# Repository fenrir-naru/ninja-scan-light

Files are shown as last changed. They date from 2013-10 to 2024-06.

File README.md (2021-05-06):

NinjaScan-Light
===============

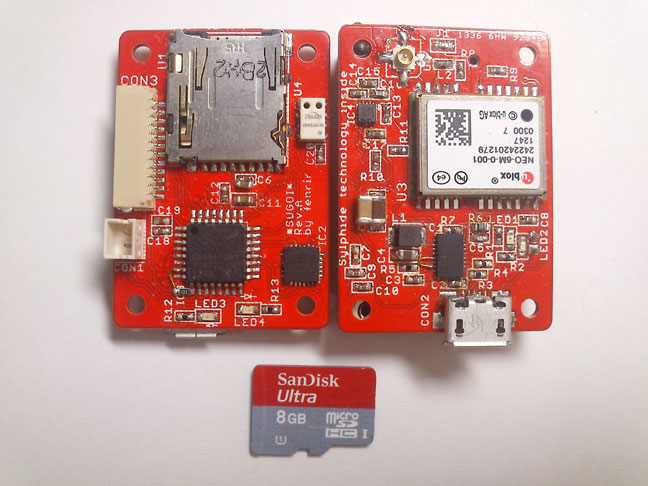
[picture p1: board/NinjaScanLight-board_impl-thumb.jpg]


[NinjaScan-Light](https://github.com/fenrir-naru/ninja-scan-light/wiki) is an ultra-small (1.0 x 1.4 inch, approximately 26 x 36 mm) motion logger. 
It consists of
 
1. Silicon Laboratories C8051F381 MCU providing USB connectability, 
1. u-blox NEO-6 series GPS receiver, 
1. 6 DOF inertial sensor, Invensense MPU-6000 (ver.1), or Invensense MPU-9250 (ver.2), 
1. 3-axis magnetic sensor, Freescale MAG3110 (ver.1), or Invensense MPU-9250 (ver.2), 
1. Pressure sensor, Measurement specialties MS5611, 
1. Power management including Li-Ion battery charger, Linear Technology LTC3550, and 
1. MicroSD supporting SDHC/FAT32. 

**More information in [Wiki](https://github.com/fenrir-naru/ninja-scan-light/wiki).**

## Additional information
* Firmware binaries are released in [github](https://github.com/fenrir-naru/ninja-scan-light/releases).
* External links for [related tools](https://fenrir-naru.github.io/archives/), and [Gerbers](https://drive.google.com/folderview?id=0ByrAl6X3Khv2TkJ5Wkp4RmhMWjg&usp=sharing).
* The project owner's website is [Fenrir's BLog](http://fenrir.naruoka.org/).





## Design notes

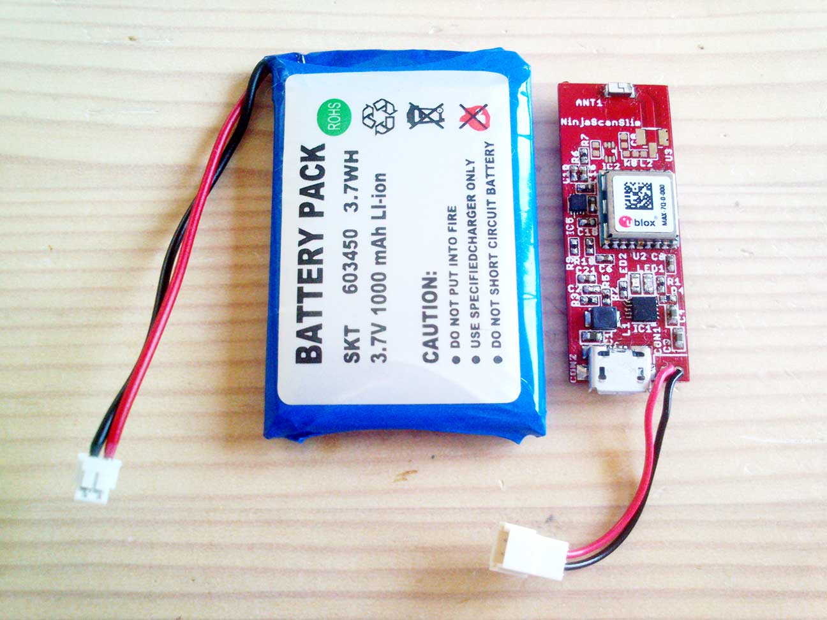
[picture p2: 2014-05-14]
board/NinjaScanSlim_RevB_with_battery.jpg

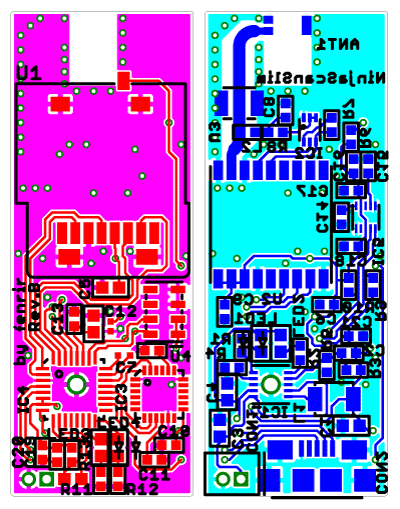
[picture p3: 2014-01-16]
board/NinjaScanSlim-layout.png

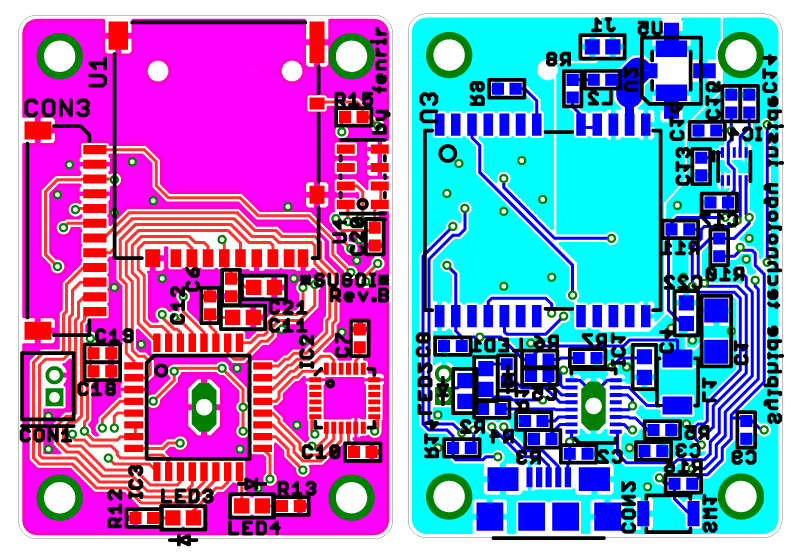
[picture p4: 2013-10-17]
board/NinjaScanLight-layout.png

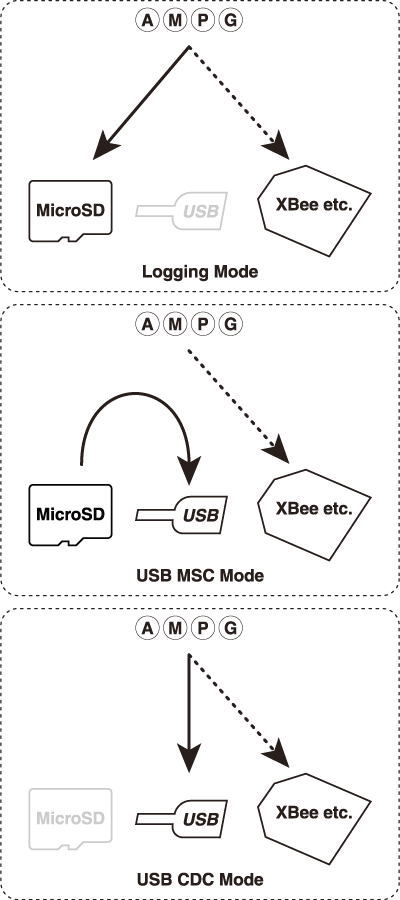
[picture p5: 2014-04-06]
firmware/misc/ninja-scan-modes.png

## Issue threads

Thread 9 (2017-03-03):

Ninjascan-light not sending data - Green and Blue LED blinking

N1N, 2017-03-03:
Hi,

I have Ninjascan-light sensor. Initially when i connected to my PC (running UBUNTU),
With the below command,
 cat /dev/ttyACM0
i was able to get the log data in to my terminal.

After sometime,it stopped sending data.But both green and blue LED's are blinking.

I tried reconnecting the device several times, but the result is same. It is getting detected as ACM0,Green and blue LED's are blinking but it is not sending any data.

Also i am getting following print in dmesg,
"string descriptor 0 read error: -32"

Please help!

Regards,
NaN

fenrir-naru, 2017-03-06:
Hi, thank you for sending me a feedback. Probably, it is a complex problem related to CDC driver and it may not a case that my developed device is just evil.
It is difficult for me to help you because I mostly focus on Windows. However, if you let me know more detail, such as packet capture of USB bus, it is great helpful.

Closed 2017-03-06.

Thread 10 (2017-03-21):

Minimize sensor data sending speed

N1N, 2017-03-21:
Hi,

I am using NinjaScan light sensor in linux. I want to capture the live sensor data.
As per my requirement,i want the sensor device to send the data exactly after 1 second,not before that.
In my application i am using read() with /dev/ttyACM0 node.

How to reduce the data sending speed of Sensor device.

Regards,
NaN

fenrir-naru, 2017-03-21:
Thank you for your comment.

The difficulty to answer your question quite depends on how precise "1 second" you said is (for instance +/- 1ns?).
At least, you have to consider the following things;
- Synchronization between OS managed time and standard time represented by UTC, or GPS time.
- How precise OS provided time functions such as sleep() is.
- IO mechanism; consideration of use of non-blocking IO.

AGAIN, I cannot provide any sufficient support for Linux, therefore, I will close this issue. If you can resolve the problem by yourself, please let me know by writing additional comments to share the know-how.

N1N, 2017-03-22:
@fenrir-naru

Thank you for the reply.

I just want to set the time interval in the sensor device,
For ex: If i set 2 seconds, the sensor device should send the data every 2 seconds.
If i go for read() before 2 seconds, sensor device should not give the data.
Any commands available to set the time interval,so that i can get the data every 'n' seconds?

Regards,
NaN

fenrir-naru, 2017-03-22:
I understood what you wanted to do. You want to reduce the output frequency of data from NinjaScan-Light.
I think the easiest way is to build a small Linux program to filter out data which is redundant for you, rather than to modify the firmware.

N1N, 2017-03-22:
Thank you.

I need to know one more information.
Whether NinjaScan supports CTS-RTS handshaking?
If yes, how to enable that?

Regards,
NaN

fenrir-naru, 2017-03-23:
I understand your case more clearly.
Currently, the SW/HW flow control capability like CTS-RTS, XON-XOFF has not been implemented. Moreover, I do not have any plan to do so in the future, because I designed the device to transmit data as much as possible.
Probably, the problem will be solved by improving your program. You had better to split the tasks of reading data from the other tasks by using multi-thread programming technique. The read task should always read data in order to reduce the possibility to encounter the buffer overflow.

N1N, 2017-03-23:
@fenrir-naru
I understand your suggestions.
But i am continuously reading the data without doing any other task. even then bytes are being lost.
If s/w and h/w flow control is not supported, then only reducing the output frequency of ninja scan device will solve the issue.
So can u please tell how to reduce output frequency?
Regards,
NaN

fenrir-naru, 2017-03-24:
The firmware modification might be difficult for you, because of both of your skill ( you have to understand the C code for 8051 microprocessor, which is unpopular unlike Arduino) and environment (you need additional debug hardware and circuit to download the modified firmware to the target).
Therefore, I strongly recommend to check your program first. please share your source code.

N1N, 2017-03-24:
@fenrir-naru

Please find the code below, which i am using to get data from ninja scan device. As i told u before, i am not doing other tasks, other than reading from the device.

I am running this code in ARM imx processor board.

int main(){
 int i = 0;
 struct termios options;
 int count = 100;
 u_int8_t sentence[2500]="";
 static const char fileSource[] ="/dev/ttyACM0";
 int counter=0;
 int fd = open(fileSource,O_RDONLY);
int in = 0;
while(count>0){
if(in>999)
break;
 counter=read(fd, sentence+in,1000);
 printf("counter %d\n",counter);
 in += counter;

count--;
}
 for(i=0;i<in;i++)
    printf("sentence[%d] %x\n",i,sentence[i]);

return 0;
}

fenrir-naru, 2017-03-24:
Thank you for sharing your code.
Could you tell me how you recognize the data is lost? One confirmation, do you know there is DIFFERENCE between the data logged to MicroSD and streamed on USB? Please check Wiki. https://github.com/fenrir-naru/ninja-scan-light/wiki/USBSerialDumpFormat

BTW, you had better to use some syntax high-lighten code sharing site such as Gist https://gist.github.com/ .

fenrir-naru, 2017-03-24:
I found a cause in your code. You have to configure termios struct as "raw" mode in order to receiver binary data without any interrupt. Please google cfmakeraw(), or see http://linuxmemonote.blogspot.jp/2010/07/linuxrs-232crs-422ttyraw.html if you can read Japanese. Also as reference, I use the following configuration for my program. https://github.com/fenrir-naru/ninja-scan-light/blob/master/tool/util/comstream.h#L319

Closed 2017-03-21.

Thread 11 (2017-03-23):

Enable software flow control in Ninja scan light sensor

shourie5794, 2017-03-23:
Hello,
I am using Ninja Scan device with imx6 board.
In my application when i do byte read,some of the bytes are lost .
I had tried this with different baud rate, but issue still exists.
I want to  know how to enable software flow control of ninja scan device.

I found similar issue discused in below link :
https://github.com/fenrir-naru/ninja-scan-light/issues/10
Thank you

fenrir-naru, 2017-03-23:
Thank you for your comment.
please see #10 .

fenrir-naru, 2017-03-23:
In addition, the baudrate setting is meaningless (dummy), because the USB-CDC implementation does not provide baudrate emulation.

Closed 2017-03-23.

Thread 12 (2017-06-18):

AK8963_CNTL2 is read only

MauroMombelli, 2017-06-18:
in mpu9250.c you set the value of AK8963_CNTL2 to reset the magnetometer, but that register is read only

MauroMombelli, 2017-06-18:
my bad, it is correct

Closed 2017-06-18.

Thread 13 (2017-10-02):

Data from telemetry connector

takespace, 2017-10-02:
Hi, I'm using chotto-sugoi logger with telemetry connector.
That's is powerful function but I got some data including data.

I couldn't get correct ubx data.
Byte data after 0x47('G')  is always 0x00.
In the same time, data from SD card is always correct.

Any body have same problem?

fenrir-naru, 2017-10-02:
Hi, thank you for your sharing the problem.
I am interested in this issue.
I want to investigate the problem more, so could you upload the SD and telemetry data which include the problem anywhere?

takespace, 2017-10-03:
Thank you for your reply.
It's OK, but it include private information....GPS data.

I found your e-mail address on blog site.
I sent you the text file.

Could you check it?

fenrir-naru, 2017-10-03:
Thank you, I received your data. I will check it.
When I have progress, I will comment here.

takespace, 2017-10-03:
Thank you for your kind.
I also try to solve this issue.
See you then.

fenrir-naru, 2017-10-04:
I saw the data you sent me.
I agree with you that the good data being in the SD but the corrupted data being in the telemetry is also strange for me.
This type of a problem should be tackled by testing possibilities one by one.
The first step is the hardware; if you use a wireless system for the telemetry, please change it to the wired, that is, direct connection and check data again?

takespace, 2017-10-04:
I got the data by FTDI<->USB adapter not wireless system.
If hardware has a problem, Page checksum will not be match.

When I check the checksum of the G page, those were totally matched.
But UBX data by those G page data did not match.
So I think it has issue before making G page check sum.
How is my guess?

fenrir-naru, 2017-10-04:
Thank you for already checking the first step. There is no problem in the hardware.
So the second step is the data amount.
I am concerned that if the telemetry data is larger than expected, it will be lost due to the slower UART rate than that of SD.
To check the possibility, could you change the content of the telemetry by putting "renew.cfg" generated with a Ruby script [renew_cfg_gen.rb](https://github.com/fenrir-naru/ninja-scan-light/blob/master/firmware/misc/renew_cfg_gen.rb) in a SD card. The 143rd to 145th lines of renew_cfg_gen.rb regulates A/P/M page  frequencies, respectively. The larger number means less frequency, therefore, 255 is the best choice for this situation.
I hope the above information is helpful to solve the problem.

fenrir-naru, 2017-10-10:
@takespace Thank you for another data, I checked it.
The data was very helpful, and I found a bug, which was clearly related to this issue.
The bug was careless, however, critical.
I fixed it with c1ea36f, please check the latest master branch including it.

fenrir-naru, 2017-10-12:
I have checked the bug fix with my hardware, and I successfully read the G page via telemetry.
A new release [v1.1.2+firmware](https://github.com/fenrir-naru/ninja-scan-light/releases/tag/v1.1.2%2BFirmware) includes the bug fix, and I will close this issue.
@takespace , if you find trouble associated with this issue, please reopen it.

takespace, 2017-10-12:
Sorry for my late reply.
I checked the firmware.
It completely worked!!

I have 1 more other issue.
I'll contact you as other issue.
Thank you so much.

Closed 2017-10-12.

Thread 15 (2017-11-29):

Interpretation and meanings of sensor values

pitaslayer, 2017-11-29:
Hello!

I'm using your "sensor board" to try out my first experiences in the hardware / sensor kind of stuff. The board works greatly and the data frequency of it is perfect for my experiences. However, I cant figured out how to translate the values from the dump file to "normal" values. For example my temperature value is 28304 and I know that the value isnt in Celsius or Fahrenheit. How can I convert to that?

Kind Regards,
T

fenrir-naru, 2017-11-29:
Hi,
Did you see [the format page in Wiki](https://github.com/fenrir-naru/ninja-scan-light/wiki/LogFile)? If you need further information, you can find it in the data sheet of the sensors.
Or, you can use the latest log_CSV binary (downloadable from Files section on [Bintray](https://bintray.com/fenrir-naru/github/ninja-scan-light/_latestVersion)), which is the standard converter of generated log.dat, with "--physical" option. Some raw values are converted into physical quantities by using this option.

Closed 2017-11-29.

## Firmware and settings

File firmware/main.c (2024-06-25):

/*
 * Copyright (c) 2015, M.Naruoka (fenrir)
 * All rights reserved.
 * 
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
 * THIS SOFTWARE IS PROVIDED BY THE COPYRIGHT HOLDERS AND CONTRIBUTORS "AS IS" 
 * AND ANY EXPRESS OR IMPLIED WARRANTIES, INCLUDING, BUT NOT LIMITED TO, 
 * THE IMPLIED WARRANTIES OF MERCHANTABILITY AND FITNESS FOR A PARTICULAR PURPOSE 
 * ARE DISCLAIMED. IN NO EVENT SHALL THE COPYRIGHT HOLDER OR CONTRIBUTORS 
 * BE LIABLE FOR ANY DIRECT, INDIRECT, INCIDENTAL, SPECIAL, EXEMPLARY, 
 * OR CONSEQUENTIAL DAMAGES (INCLUDING, BUT NOT LIMITED TO, 
 * PROCUREMENT OF SUBSTITUTE GOODS OR SERVICES; 
 * LOSS OF USE, DATA, OR PROFITS; OR BUSINESS INTERRUPTION) 
 * HOWEVER CAUSED AND ON ANY THEORY OF LIABILITY, WHETHER IN CONTRACT, 
 * STRICT LIABILITY, OR TORT (INCLUDING NEGLIGENCE OR OTHERWISE) 
 * ARISING IN ANY WAY OUT OF THE USE OF THIS SOFTWARE, 
 * EVEN IF ADVISED OF THE POSSIBILITY OF SUCH DAMAGE.
 * 
 */

#include <stdio.h>
#include <time.h>

#include "main.h"
#include "util.h"
#include "config.h"

#include "c8051f380.h"
#include "f38x_usb.h"
#include "f38x_uart0.h"
#include "f38x_uart1.h"
#include "f38x_i2c.h"
#include "f38x_spi.h"

#include "data_hub.h"

#include "gps.h"
#include "telemeter.h"
#if defined(NINJA_VER) && (NINJA_VER >= 200)
#include "mpu9250.h"
#else
#include "mpu6000.h"
#include "mag3110.h"
#endif
#include "ms5611.h"
#if defined(I2C0_RV3129)
#include "rv3129.h"
#endif
#if defined(I2C1_ADS122)
#include "ads122.h"
#elif defined(I2C1_ELVR)
#include "all_sensors_elvr.h"
#endif

volatile __xdata u32 global_ms = 0;
volatile __xdata u32 tickcount = 0;
volatile __xdata u8 sys_state = 0;
volatile u8 timeout_10ms = 0;

__xdata void (*main_loop_prologue)() = NULL;

static void sysclk_init();
static void port_init();
static void timer_init();

typedef struct {
  long delay_sec;
} software_reset_survive_t;

static __idata __at (0x100 - sizeof(software_reset_survive_t))
    software_reset_survive_t software_reset_survive;

#ifdef USE_ASM_FOR_SFR_MANIP
#define p21_hiz()   {__asm orl _P2,SHARP  0x02 __endasm; }
#define p21_low()   {__asm anl _P2,SHARP ~0x02 __endasm; }
#define scl0_hiz()  {__asm orl _P1,SHARP  0x02 __endasm; }
#define scl0_low()  {__asm anl _P1,SHARP ~0x02 __endasm; }
#define scl1_hiz()  {__asm orl _P2,SHARP  0x80 __endasm; }
#define scl1_low()  {__asm anl _P2,SHARP ~0x80 __endasm; }
#define led3_on()   {__asm orl _P2,SHARP  0x08 __endasm; }
#define led4_on()   {__asm orl _P2,SHARP  0x04 __endasm; }
#define led34_on()  {__asm orl _P2,SHARP  (0x04 | 0x08) __endasm; }
#define led34_off() {__asm anl _P2,SHARP ~(0x04 | 0x08) __endasm; }
#else
#define p21_hiz()   (P2 |=  0x02)
#define p21_low()   (P2 &= ~0x02)
#define scl0_hiz()  (P1 |=  0x02)
#define scl0_low()  (P1 &= ~0x02)
#define scl1_hiz()  (P1 |=  0x80)
#define scl1_low()  (P1 &= ~0x80)
#define led3_on()   (P2 |=  0x08)
#define led4_on()   (P2 |=  0x04)
#define led34_on()  (P2 |=  (0x04 | 0x08))
#define led34_off() (P2 &= ~(0x04 | 0x08))
#endif

#define software_reset() {RSTSRC = 0x10;} // RSTSRC.4(SWRSF) = 1 causes software reset

static void power_on_delay_check(FIL *f){
  // extract standby time[s] from file
  software_reset_survive.delay_sec = data_hub_read_long(f);
}

static void power_on_delay(){
  if((REG01CN & 0x40) || (RSTSRC & 0x02) || (!(RSTSRC & 0x10))
      || (software_reset_survive.delay_sec <= 0)){
    // Skip either when USB is connected, software reset is not invoked, or no delay
    software_reset_survive.delay_sec = 0;
    return;
  }

  /* How to standby with minimum power consumption
   * 1-1. Set all pins are configured as Hi-Z (open-drain and H) (except for P0.4, P2.2, P2.3).
   * 1-2. Sleep GPS
   * 1-3. Shutdown LTC3550 buck regulator by pulling P2.1 to L (Effective only for ver.2)
   * 1-4. Enable the low frequency internal oscillator
   * 2-1. Selecting the low frequency oscillator
   * 2-2. Disable unused peripherals including the high frequency oscillator
   * 2-3. Standby for the specified time
   * 3-1. Wake GPS up
   * 3-2. Perform software reset.
   */

  // step 1
  // P1MDOUT = P3MDOUT = 0; // default
  P0MDOUT = 0x10;
  P2MDOUT = (0x04 | 0x08);
  // P0 = P1 = P3 = 0xFF; // default
  P2 = ~(0x04 | 0x08);
  XBR0 = 0x01;  // Enable UART0
  XBR1 = 0xC0;  // Enable crossbar & Disable weak pull-up

  uart0_init_boot();
  gps_sleep();

  p21_low();

  OSCLCN = 0x82; // enable low frequency OSC with 40KHz output config
  while(!(OSCLCN & 0x40)); // wait for ready

  // step 2
  //TMR3CN = 0x00;    // Stop Timer3; Clear TF3; default
  CKCON |= 0xC0;   // Timer3 clocked based on SYSCLK;
  TMR3RL = (0x10000 - 40000);  // Re-initialize reload value (40KHz, 1s)
  TMR3 = 0xFFFF;    // Set to reload immediately
  CLKSEL = (CLKSEL & ~0x07) | 0x04; // Select L-F oscillator

  OSCICN &= ~0x80; // Disable H-F oscillator

  TMR3CN |= 0x04;   // Start Timer3(TR3)
  do{
    if(software_reset_survive.delay_sec & 0x0F){led34_off();}else{led34_on();}
    while(!(TMR3CN & 0x80));
    TMR3CN &=~0x80;
  }while((--software_reset_survive.delay_sec) > 0);

  // step 3
  gps_wakeup();
  software_reset();
}

#if defined(POSITION_MONITOR)
typedef struct {
  gps_pos_t upper, lower;
  u8 polarity;
} position_range_t;
#define POSITION_RANGE_POLARITY_NEG 0x10
static volatile __code __at(CONFIG_ADDRESS + sizeof(config_t))
    position_range_t position_range = {
  {{ // position upper
    1800000000, 900000000, 100000000, // E180, N90, 100km
  }},
  {{ // position lower
    -1800000000, -900000000, -100000000, // W180, S90, -100km
  }},
  0x7, // 0bXXX[!]_X[H][lat][lng]; default: required condition is lower < target < upper, neither target < lower nor upper < target
};
static void position_monitor(__xdata gps_pos_t *pos){
  typedef enum {
    GPS_SAT_0 = 0,
    GPS_SAT_1 = 1,
    GPS_SAT_2 = 2,
    GPS_SAT_3 = 3,
    GPS_OUT_OF_RANGE,
    GPS_IN_RANGE,
  } gps_state_t;
  static __xdata gps_state_t periodic = GPS_SAT_0;
  static __xdata u16 periodic_count = 0;
  gps_state_t current = GPS_OUT_OF_RANGE;
  switch(gps_fix_type){
    case GPS_FIX_3D:
    case GPS_FIX_DEAD_RECKONING_COMBINED:
      if(gps_pos_accuracy >= GPS_POS_ACC_100M){
        u8 i, j, in_range = POSITION_RANGE_POLARITY_NEG;
        for(i = 0, j = 0x01; i < 3; ++i, j <<= 1){
          u8
              a = (position_range.upper.v[i] < pos->v[i]),
              b = (position_range.lower.v[i] > pos->v[i]);
          if((position_range.polarity & j) ? (a || b) : (a && b)){
            in_range = 0x00;
            break;
          }
        }
        current = ((position_range.polarity & POSITION_RANGE_POLARITY_NEG) ^ in_range)
            ? GPS_IN_RANGE : GPS_OUT_OF_RANGE;
      }
      break;
    default:
      if(gps_num_of_sat < 4){
        current = (gps_state_t)gps_num_of_sat;
      }
  }
  if(periodic < current){periodic = current;}
  if(usb_mode != USB_INACTIVE){
    periodic_count = 0;
    return;
  }
  ++periodic_count;
  if(periodic <= GPS_SAT_3){
    if(periodic_count >= 0x800){ // Timeout 409.6 [s] @ 5Hz
      software_reset_survive.delay_sec = 900; // Sleep 15 min.
      software_reset();
    }
  }else if(periodic <= GPS_OUT_OF_RANGE){
    if(periodic_count >= 0x100){ // Timeout 51.2 [s] @ 5Hz
      software_reset_survive.delay_sec = 120; // Sleep 2 min.
      software_reset();
    }
  }else{
    if(periodic_count >= 0x100){
      periodic = GPS_SAT_0;
      periodic_count = 0;
    }
  }
}
static void position_check(FIL *f){
  if(f_size(f)){ // check new configuration
    // file format must be "lng_upper lng_lower lat_upper lat_lower alt_upper alt_lower"
    DWORD f_pos = f_tell(f);
    __xdata config_t *buf = config_clone();
    __xdata position_range_t *buf_range = (__xdata position_range_t *)((u8 *)buf + sizeof(config_t));
    u8 i, j;
    buf_range->polarity = 0;
    for(i = 0, j = 0x1; i < 3; ++i, j <<= 1){
      buf_range->upper.v[i] = data_hub_read_long(f);
      buf_range->lower.v[i] = data_hub_read_long(f);
      if(f_tell(f) == f_pos){break;}
      f_pos = f_tell(f);
      if(buf_range->upper.v[i] >= buf_range->lower.v[i]){
        buf_range->polarity |= j;
      }
    }
    if(data_hub_read_long(f) > 0){
      buf_range->polarity |= POSITION_RANGE_POLARITY_NEG;
    }
    if((i == 3) && (memcmp(&position_range, buf_range, sizeof(position_range_t)) != 0)){
      config_renew(buf);
    }
  }
  gps_position_monitor = position_monitor;
}
#endif

void main() {
  sysclk_init(); // Initialize oscillator
  wait_ms(1000);
  port_init(); // Initialize crossbar and GPIO

  spi_init();
  data_hub_init();

  if(!(REG01CN & 0x40)){
    // When USB is disconnected
    if(RSTSRC & 0x02){
      // When initial power on, which causes power on reset (RSTSRC.1(PORSF) = 1).
      data_hub_load_config("DELAY.CFG", power_on_delay_check);
      if(software_reset_survive.delay_sec > 0){software_reset();}
    }
#if defined(POSITION_MONITOR)
    data_hub_load_config("POSITION.CFG", position_check);
#endif
  }

  timer_init();
  uart0_init();
  uart1_init();
  i2c_init();

#if defined(NINJA_VER) && (NINJA_VER >= 200)
  mpu9250_init();
#else
  mpu6000_init();
  mag3110_init();
#endif
  ms5611_init();
#if defined(I2C0_RV3129)
  rv3129_init();
#endif
#if defined(I2C1_ADS122)
  ads122_init();
#elif defined(I2C1_ELVR)
  as_elvr_init();
#endif
  
  EA = 1; // Global Interrupt enable
  
  gps_init();
  telemeter_init();

  usb0_init();

  // Time Pulse Interrupt config (-INT0)
  IT0 = 1;    // Edge sense
  //PX0 = 1;    // Priority High
  EX0 = 1;    // Enable

  while(main_loop_prologue){
    main_loop_prologue();
  }

  while (1) {
    gps_polling();
    telemeter_polling();
#if defined(NINJA_VER) && (NINJA_VER >= 200)
    mpu9250_polling();
#else
    mpu6000_polling();
    mag3110_polling();
#endif
    ms5611_polling();
#if defined(I2C0_RV3129)
    rv3129_polling();
#endif
#if defined(I2C1_ADS122)
    ads122_polling();
#elif defined(I2C1_ELVR)
    as_elvr_polling();
#endif
    data_hub_polling();
    usb_polling();

    sys_state |= SYS_POLLING_ACTIVE;
  }
}

// System clock selections (SFR CLKSEL)
#define SYS_INT_OSC              0x00        // Select to use internal oscillator
#define SYS_4X_MUL               0x03        // Select to use internal oscillator
#define SYS_EXT_OSC              0x01        // Select to use an external oscillator
#define SYS_4X_DIV_2             0x02

// USB clock selections (SFR CLKSEL)
#define USB_4X_CLOCK             0x00        // Select 4x clock multiplier, for USB Full Speed
#define USB_INT_OSC_DIV_2        0x10        // See Data Sheet section 13. Oscillators
#define USB_EXT_OSC              0x20
#define USB_EXT_OSC_DIV_2        0x30
#define USB_EXT_OSC_DIV_3        0x40
#define USB_EXT_OSC_DIV_4        0x50

static void sysclk_init(){
  REF0CN = 0x07;
  
  // Configure internal oscillator for its maximum frequency and enable missing clock detector
  OSCICN |= 0x03;

#ifdef _USB_LOW_SPEED_
  CLKSEL  = SYS_INT_OSC; // Select System clock
  CLKSEL |= USB_INT_OSC_DIV_2; // Select USB clock
#else
  // Select internal oscillator as input to clock multiplier
  CLKMUL  = 0x00;
  CLKMUL |= 0x80; // Enable clock multiplier
  wait_ms(1); // Delay for clock multiplier to begin
  CLKMUL |= 0xC0; // Initialize the clock multiplier
  wait_ms(1);
  while(!(CLKMUL & 0x20)); // Wait for multiplier to lock
  CLKSEL = SYS_4X_MUL;
  CLKSEL |= USB_4X_CLOCK; // Select USB clock
#endif  /* _USB_LOW_SPEED_ */
}


static void port_init() {
  
  // Default port state
  // Pn = 1 (High), PnMDIN = 1 (not analog), PnMDOUT = 0 (open-drain) => Hi-Z

  // check scl0(P1.1) and sda0(P1.0), if not Hi, perform clock out to reset I2C0.
  while((P1 & 0x03) != 0x03){
    scl0_low();
    while(P1 & 0x02);
    scl0_hiz();
    while(!(P1 & 0x02));
  }
  
#if defined(I2C1_ADS122) || defined(I2C1_ELVR)
  // check scl1(P2.7) and sda1(P2.6), if not Hi, perform clock out to reset I2C01
  while((P2 & 0xC0) != 0xC0){
    scl1_low();
    while(P2 & 0x80);
    scl1_hiz();
    while(!(P2 & 0x80));
  }
#endif
  
  // P0
  // 0 => SPI_SCK, 1 => SPI_MISO, 2 => SPI_MOSI, 3 => SPI_-CS,
  // 4 => UART0_TX, 5 => UART0_RX, 6 => -INT0, 7 => VREF(analog)
  P0MDIN = 0x7F;
  P0MDOUT = 0x1D; // 1, 5, 6, 7 => open-drain
  P0 = 0x7F;
  P0SKIP = 0xC0;  // for -INT0 / VREF
  IT01CF = 0x76;  // -INT0 => 6 negative
  
  // P1
  // 0 => I2C0_SDA, 1 => I2C0_SCL, 2-3 => GPIO0-1,
  // 4 => IMU_SCK, 5 => IMU_MOSI, 6 => IMU_-CS, 7 => IMU_MISO
  P1MDIN = 0xFF;
  P1MDOUT = 0x7C; // 0, 1, 7 => open-drain
  P1 = 0xFF;
  P1SKIP = 0xFC;
  
  // P2
  // 0-1 => N.C., 2 => LED4, 3 => LED3
  // 4 => UART1_TX, 5 => UART1_RX, 6 => I2C1_SDA, 7 => I2C1_SCL
  P2MDIN = 0xFF; 
  P2MDOUT = 0x1C; // 0, 1, 5, 6, 7 => open-drain
  P2 = 0xF3;
  P2SKIP = 0x0F;
  
  // P3
  P3MDIN = 0xFF;
  P3MDOUT = 0xFF;
  P3 = 0x00;

  XBR0 = 0x07;  // UART0, SPI, I2C0 enabled
  XBR2 = 0x03;  // UART1, I2C1 enabled
  XBR1 = 0xC0;  // Enable crossbar & Disable weak pull-up
}

static void timer_init(){
  TMR3CN = 0x00;    // Stop Timer3; Clear TF3;
  CKCON &= ~0xC0;   // Timer3 clocked based on T3XCLK;
  TMR3RL = (0x10000 - (SYSCLK/12/100));  // Re-initialize reload value (100Hz, 10ms)
  TMR3 = 0xFFFF;    // Set to reload immediately
  EIE1 |= 0x80;     // Enable Timer3 interrupts(ET3)
  TMR3CN |= 0x04;   // Start Timer3(TR3)
}

/**
 * interrupt routine invoked when timer3 overflow
 * 
 */
void interrupt_timer3() __interrupt (INTERRUPT_TIMER3) {

  static u8 loop_50ms = 0;
  static u8 snapshot_gps = 0;
  static u8 snapshot_state = 0;
  static u8 loop_10s = 0;

  {
    u8 sfrpage_backup = SFRPAGE;
    SFRPAGE = 0;
    TMR3CN &= ~0x80; // Clear interrupt
    SFRPAGE = sfrpage_backup;
  }
#if defined(NINJA_VER) && (NINJA_VER >= 200)
  mpu9250_capture = TRUE;
#else
  mpu6000_capture = TRUE;
#endif
  global_ms += 10;
  tickcount++;
  timeout_10ms++;
  switch(u32_lsbyte(tickcount) % 16){ // 6.25Hz
    case 0:
#if defined(I2C1_ADS122)
      ads122_capture = TRUE;
#elif defined(I2C1_ELVR)
      as_elvr_capture = TRUE;
#endif
      break;
    case 4:
#if !(defined(NINJA_VER) && (NINJA_VER >= 200))
      mag3110_capture = TRUE;
#endif
      break;
    case 8:
      ms5611_capture = TRUE; // Read pressure
      break;
    case 12:
      ms5611_capture = TRUE; // Read temperature
      break;
  }

  if(++loop_50ms < 5){return;}
  loop_50ms = 0;

  switch(++loop_10s % 5){
    case 0:
      if(loop_10s % 8 == 0){ // 50 * 5 * 8 = 2000 [ms]
        snapshot_state = (SYS_PERIODIC_ACTIVE | sys_state);
        sys_state = 0;
        if(loop_10s >= 200){ // 50 * 200 = 10000 [ms]
          loop_10s = 0;
          snapshot_gps = gps_num_of_sat;
        }
      }
      if(snapshot_gps > 0){
        led4_on();
        snapshot_gps--;
      }
      if(snapshot_state & 0x01){
        led3_on();
      }
      break;
    case 1:
      led34_off(); // LED3 / 4 off
      snapshot_state >>= 1;
      break;
  }
}

void interrupt_int0() __interrupt(INTERRUPT_INT0) {
  if(gps_time_modified){
    gps_time_modified = FALSE;
    global_ms = gps_time.itow_ms;
  }
}

DWORD get_fattime(){
  static __xdata DWORD res = 0;
#if USE_GPS_STD_TIME
  struct tm *t;
  time_t timer;
  gps_std_time(&timer);

  if(timer == 0){return res;}
  t = localtime(&timer);
#define GET_TM_ITEM(x) t->x
#else
  if(!gps_utc_valid){return res;}
#define GET_TM_ITEM(x) gps_utc.x
#endif

  // bit31:25 => year - 1980
  res = GET_TM_ITEM(tm_year) + 1900 - 1980;
  res <<= 4;
  // bit24:21 => month[1..12]
  res |= GET_TM_ITEM(tm_mon) + 1;
  res <<= 5;
  // bit20:16 => day[1..31]
  res |= GET_TM_ITEM(tm_mday);
  res <<= 5;
  // bit15:11 => hour[0..23]
  res |= GET_TM_ITEM(tm_hour);
  res <<= 6;
  // bit10:5 => minute[0..59]
  res |= GET_TM_ITEM(tm_min);
  res <<= 5;
  // bit4:0 => second / 2
  res |= GET_TM_ITEM(tm_sec) / 2;

  return res;
}

unsigned char _sdcc_external_startup(){
  PCA0MD &= ~0x40; ///< Disable Watchdog timer
  power_on_delay();
  return 0;
}

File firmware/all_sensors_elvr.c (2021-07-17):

#include "all_sensors_elvr.h"
#include "main.h"

#include <string.h>

#include "f38x_i2c.h"
#include "data_hub.h"
#include "util.h"
#include "c8051f380.h"

#define I2C_ADDRESS_RW (0x78 << 1)

static __xdata u8 as_elvr_data[SYLPHIDE_PAGESIZE - 8];

/*
 * X page design =>
 * 'X', 0, 0, tickcount & 0xFF, // + 4
 * global_ms(4 bytes), // + 8
 * [0..11] pressure value(2bytes, big endian?) // + 32
 */

volatile __bit as_elvr_capture;

//#define i2c_read_write i2c0_read_write
#define i2c_read_write i2c1_read_write

void as_elvr_init(){
  as_elvr_capture = FALSE;
}

static void make_packet(packet_t *packet){
  payload_t *dst = packet->current;
  
  // Check whether buffer size is sufficient
  if((packet->buf_end - dst) < SYLPHIDE_PAGESIZE){
    return;
  }
    
  *(dst++) = 'X';
  *(dst++) = 1;
  *(dst++) = 0;
  *(dst++) = u32_lsbyte(tickcount);
  
  // Record time, LSB first
  memcpy(dst, &global_ms, sizeof(global_ms));
  dst += sizeof(global_ms);
  
  memcpy(dst, as_elvr_data, sizeof(as_elvr_data));
  dst += sizeof(as_elvr_data);
  
  packet->current = dst;
}

void as_elvr_polling(){
  
  static __xdata u8 * __xdata next_buf = as_elvr_data;
  
  if(as_elvr_capture){
    as_elvr_capture = FALSE;
    
    i2c_read_write(I2C_READ(I2C_ADDRESS_RW), next_buf, 2);
    next_buf += 2;

    if(next_buf == (as_elvr_data + sizeof(as_elvr_data))){
      // Rotate
      data_hub_assign_page(make_packet);
      next_buf = as_elvr_data;
    }
  }
}

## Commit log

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2013-09-22 Change name
    [NinjaScanLight.brd, NinjaScanLight.sch]
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2013-09-27 Add pull-up register to -RST/C2CK net. Move R7 for soldering ease.
    [NinjaScanLight.brd, NinjaScanLight.sch]
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2013-09-28 Use Communication Device Clas (CDC) as USB serial feature. Use SOF invoker to take care of CDC communication endpoint.
2013-10-04 Keep block length instead of total (physical) size, because SDHC capacity will be larger than 4 GB, which is limit to be represented by 32-bit long.
2013-10-04 MPU-6000 now works correctly with sdcc 2.7.0. Replace tabs to white spaces.
    [main.c, mpu6000.c]
2013-10-04 Optimize component position.
    [NinjaScanLight.brd, NinjaScanLight.sch]
2013-10-06 * Add inline assembler code to manipulate I/O, this is work around for current sdcc (maybe newer than 2.7.0). * Optimize mmc code.
2013-10-09 Add U.FL GPS antenna connector pattern. Add C21/C22 for reinforcement of +3V line.
    [NinjaScanLight.brd, NinjaScanLight.sch]
2013-10-09 Optimize component position
    [NinjaScanLight.brd, NinjaScanLight.sch]
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2013-10-13 * Improve UART FIFO buffer access, especially for interrupt routine. * Add storage class for fifo buffer to speed up to access memory by removing _gptrput/get functions.
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2013-10-13 * Change PORT_MANIP to SFR_MANIP * Add asm routine to manipulate interrupt enable flags.
2013-10-15 Correct P page format.
    [log_CSV.cpp]
2013-10-16 * Manage usb status with usb_mode variable instead of usb_enable, usb_previous_enable flags. * Logging to MicroSD function is available when power is supplied via USB and USB does not have any connec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
2013-10-16 * Manage usb status with usb_mode variable instead of usb_enable, usb_previous_enable flags. * Logging to MicroSD function is available when power is supplied via USB and USB does not have any connec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
    [data_hub.c]
2013-10-16 Correct array index to obtain exact pressure and temperature.
    [log_CSV.cpp]
2013-10-17 Add utility switch.
    [NinjaScanLight.brd, NinjaScanLight.sch]
2013-10-19 Correct error to stop logging unintentionally when usb_mode is changed.
    [data_hub.c]
2013-10-22 Correct "msd" to "msc", because "Mass storage class", not "Mass storage device".
    [data_hub.c]
2013-10-25 * Correct PID
2013-10-29 Change initial usb_state considering USB_VBUS. If USB cable connection is detected, 100ms wait is inserted to determine whether the cable is connected to PC or battery. If cable is connected to PC, u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
2013-12-16 Corresponds to r7808 on the original repository.
    [NinjaScanSlim.brd, NinjaScanSlim.sch]
2013-12-16 Change I2C pull-up registers by 2K ohm. corresponds to r7810 on the original repository.
    [NinjaScanSlim.brd, NinjaScanSlim.sch]
2014-01-22 Add cdc_force flag to be recognized as CDC device even when MicroSD is inserted.
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2014-03-28 Add gps additional configuration feature with gps.cfg stored in MicroSD.
    [for_neo6m_rename_to_gps.cfg]
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2014-04-02 Correct telemetry transfer size to PAGE_SIZE.
    [data_hub.c]
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2014-04-03 Correct range for CRC calculation.
    [data_hub.c]
2014-04-22 Add internal antenna, which corresponds to r7833 of the original repository.
    [NinjaScanSlim.brd, NinjaScanSlim.sch]
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2014-04-23 Add XYZ silk.
    [NinjaScanSlim.brd]
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2014-08-15 Revise SDA2 and SCL2 of MAX-6Q, which were opposite.
    [NinjaScanSlim.sch]
2014-10-23 Correct output control of G page.
    [log_CSV.cpp]
2014-10-30 Fix time renewal problem by using buffer.
    [main.c]
2015-01-10 Change from MPU-6000 & MAG3110 comb. of NinjaScan-Light to MPU-9250 single chip.
    [NinjaScanLight2.brd, NinjaScanLight2.sch]
2015-01-10 Fix airwire.
    [NinjaScanLight2.brd]
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2015-01-11 Modify power line for sleep feature, and add circuit of GPS backup battery.
    [NinjaScanLight2.brd, NinjaScanLight2.sch]
2015-01-11 Improve GND pattern.
    [NinjaScanLight2.brd]
2015-01-12 Change nets connected with SW1.
    [NinjaScanLight2.brd, NinjaScanLight2.sch]
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2015-01-25 Change R17 (charging current limiter) from 4.7K to 2K ohm.
    [NinjaScanLight2.brd, NinjaScanLight2.sch]
2015-06-16 Tune gyro bias drift Q, and add time sync. feature for initialization.
2015-06-18 Add reducing 1pps sync error feature.
    [log_CSV.cpp]
2015-06-18 Tune accelerometer bias drift Q.
2015-10-04 Fix check_spec()s override feature, and improve them.
    [log_CSV.cpp]
2015-10-05 Fix false response which occurs keyword in calibration file is shorter
2016-02-17 Move direct connection to data_hub, and not only uart0, but also uart1.
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2016-02-24 Fix include file name for case sensitive environment
    [f38x_spi.c]
2016-02-28 Add overwrite prevention scheme after configuration renewal
    [data_hub.c]
2016-03-20 Fix baudrate changer setup timing
    [data_hub.c]
2016-03-23 Fix unreflected initial baudrate when direct mode is activated
    [data_hub.c]
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2016-08-16 Fix miscalculation of velocity component of linearized equation.
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2016-08-22 Decrease initial variance corresponding to gyroscope bias drift
2016-09-14 Refactoring (and fix); standardize time comparison operations
    [log_CSV.cpp]
2016-10-06 Fix to monitor GPS week number always.
    [log_CSV.cpp]
2016-10-06 Add Cygwin support with replacement to SYLPHIDE_PAGE_SIZE
    [log_CSV.cpp]
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2017-01-28 Refactoring; move correct_info and correct_yaw to Filtered_INS2.
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2017-01-29 Refactoring; correct with arm depends on Filtered_INS_BiasEstimated.
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2017-03-09 Separate NAVData from INS_GPS_Back_Propagate.
    * Currently, --back_propagte option does not work, because the function
    to extract snapshots from INS_GPS_Back_Propagate has been removed.
    * Optimize INS_GPS_Back_Propagate and INS_GPS_RealTime by using instance
    instead of new().
2017-03-26 Optimize storage.
    * Angular speed for lever arm is calculated with "recent_a_packets",
    which was previously done with another specific "gyro_storage".
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2017-05-01 Update with generic packet mechanize for non-realtime scheme.
    * Currently, support only one stream.
    * Dumping results after update should be changed to take no output case
    into account.
2017-05-11 Refactoring and Optimization.
    * STL container must be inherited as protected or private.
2017-05-11 Fix memory leak and simplify Packet clone and apply strategy.
    * virtual destructor must be implemented in Packet.
    * Move functionality from StreamProcessor::latest_packet to Packet.
    Currently it is realized by virtual functions of Packet.
2017-06-02 Refactoring overloaded functions.
    * Change setup_filter2 to setup_filter.
    * Split init_misc into filter and non-filter versions.
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2017-07-10 Fix ubx part in case log contains only one measurement.
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2017-10-30 Fix incorrect calendar time by using timegm().
    * It is due to mktime(), which is affected by locale.
    [log_CSV.cpp]
2017-10-30 Fix timegm() missing on Windows by using _mkgmtime() instead.
    [log_CSV.cpp]
2017-11-03 Fix VC2010 syntax error.
    [log_CSV.cpp]
2017-11-10 Replace converter and calendar_time relation and perform refactoring.
    * Previously converter and calendar_time were enclosure and inner class
    respectively, however, currently inverted.
    [log_CSV.cpp]
2017-11-10 Fix build error related to type and template.
    [log_CSV.cpp]
2017-11-29 Add --physical option for physical unit outputs.
    * It supports A and P pages (acceleration, angular speed, pressure, and
    temperature). M page support is provisional.
2017-11-29 Fix MSVC2010 build error.
    [log_CSV.cpp]
2017-12-01 Optimizing matrix calculation.
    * Currently matrix view consisting of transpose, partial, row/column
    vectors, coMatrix are not fully supported. They are altered by using
    dense matrices.
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2017-12-17 Fix decomposeLU() and optimize inverse().
    * Fix LU decomposition failure when diagonal element equals to zero.
    * Reduce redundant loop.
    * Add test in case diagonal element equals to zero.
2017-12-19 Change INS_EGM template argument to PureINS
    * This is a preparation of insertion of NAVData between INS and
    FilteredINS to reduce section by removing redundant proxy functions such
    as latitude().
2017-12-19 Add INS_NAVData between INS and Filtered_INS.
    * INS_NAVData is split from INS_GPS_NAVData.
2017-12-23 Add INS_GPS_Factory.h
    * INS_GPS2 has just one template parameter.
    * INS_GPS_Factory builds appropriate INS/GPS structure, however,
    currently requiring proper order of calling.
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2018-01-18 Add geomagnetic_latlng() for each model and do refactoring.
    * Inheritance is changed; Only IGRF11 and IGRF12 Preset classes which
    hold preset models have inheritance relation. This is workaround of
    ambiguous definition of MagneticFieldGeneric functions in multiple
    inheritance style.
    * INS_GPS.cpp and NavigationModel.i are changed due to modification of
    MagneticField.h.
2018-01-18 Fix build error of MSVC2010.
    * IGRF1XGeneric::Preset are moved to IGRF1XPreset, because instantiation
    (accidentally?) failed in INS_GPS build. MSVC2017 can resolve the
    problem, therefore it seems to be a bug.
    * MSVC cannot calculate size of IGRF1XGeneric::models[] in
    MagneticFieldGeneric2, therefore, models_num constant is added.
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2018-01-24 Add u-blox M8T GPS configuration file enabling RAWX, SFRBX with SBAS.
    [for_neom8t_rename_to_gps.cfg]
2018-04-10 Add format command (currently, test failed, error code is 12).
    [main_dd.c]
2018-04-10 Fix format procedure; mount is required before mkfs
    [main_dd.c]
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2018-04-19 Change power on delay sequence
    Previously, the power on delay sequence was initial power on, delay,
    then, software reset. However, currently, initial power on, software
    reset, delay, then, software reset again, because of usability of power
    on delay routine.
    [main.c]
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2018-04-24 Fix power_on_reset issues
    * Change power_on_delay() invocation to _sdcc_external_startup(),
    because idata is cleared before main().
    * Crossbar activation is required to use GPIO
    * When RSTSRC.1 is 1, all other RSTSRC flags are indeterminate.
    [main.c]
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2018-05-05 Integrate preparation loop of GPS monitor into main loop
    * position_monitor() is changed as software reset source
    [main.c]
2018-12-25 Add size limitation per a log.dat file
    * Automatic replacement of log.dat file name when file size exceeds
    predefined maximum is also implemented.
    [data_hub.c]
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2019-02-22 Add load function of a calibration file to log_CSV
    * load_calibration_file() in analyze_common.h is created by moving
    corresponding codes from INS_GPS.cpp for reusing
2019-03-21 Optimize Matrix by decreasing "new"
    * Change Matrix::storage from storage_t * to storage_t
    * Fix bug of Array2D_Desnse::operator=; ref must be assigned to NULL
    once before evaluation of values in case values equals to NULL.
    * Add Array2D to pure virtual functions to be implemented with its
    subclasses.
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2019-04-16 Fix to insert count column to A page CSV when --physical
    [log_CSV.cpp]
2019-04-17 Fix roll over detection when --calendar_time
    * A problematic case was GPS second reported by the receiver was nearly
    end of week at the beginning of log, where itow was counting up around
    zero. In this case, the itow subtracted by GPS second was less than
    minus half of week, and roll over was falsely detected.
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2019-06-10 Fix roll over monitor in case input is far greater than previous
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2020-04-05 Fix CalendarTime::Converter bug; wrong assumption of integer seconds.
    * The first argument of update() is gps_sec, which may have fractional
    subseconds. On the other hands, the type of utc_time, which is
    calculated from update(), is time_t as integer. Therefore, std::floor
    should be inserted before calculation.
    * Merging convert()
2020-04-07 Fix Windows wrong filtered stdout output by changing mode to binary
    [log_CSV.cpp]
2020-04-20 Fix conversion from physical to ADC values by using round
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2020-06-17 Change fixed matrix structure (foce_symmetric/diagonal test failed)
    * Matrix_Frozen for fixed matrix has buffer instead of Matrix. This is
    because many Matrix_Frozen functions require Matrix_Frozen and life of
    buffer should be maintained at least for function.
    * Array2D_Fixed has two modes dependent on association of buffer; its
    switch is the forth template parameter named has_buffer.
    * Build errors occurred due to generation of Matrix_Frozen<T,
    Array2D_fixed<T, nR, nC, false>, SpecialView> in
    as_symmetric/diagonal().
    For correction, Array2D_fixed<T, nR, nC, true> should be generated for
    view transformation.
2020-06-19 Add two template parameters to Array2D_Operator_Multiply
    * Array2D_Operator_Multiply has four parameters; LHS_T, RHS_T,
    LHS_BufferT, and RHS_BufferT. The additional two parameters
    L(R)HS_BufferT are buffer class to preserve instance as is.
    * Matrix_Fixed::operator/(Matrix) works correctly now.
    * Due to this change, a test related to inspect() failed (currently,
    commented out)
2020-07-03 Separate Array2D_Operator_Multiply into by matrix and by scalar
    * Heavily changed.
    * TODO: Currently tests for matrix divided by matrix, and scalar divided
    by matrix are commented out because of build errors.
    * Matrix_fixed multiplication ia optimized by separating buffer (i.e.
    Matrix_Fixed) from functions (i.e. Matrix_Frozen)
2020-07-04 Fix to pass build of (scalar / matrix)
    * Currently, matrix_inspect tests fail because operator of (matrix *
    scalar) is implemented in nested class of
    Array2D_Operator_Multiply_by_Scalar.
2020-07-11 Add operator/(matrix) to special matrix
    * This operator is not supported for fixed size matrix currently.
    * Tests of friend operator/(scalar, matrix) are also added, however
    skipped because of provision.
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2020-08-24 Fix comment about TMR5CN on SFR Page=F
    [c8051f380.h]
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2020-09-23 Make loosely-coupled available with NAV-HPPOSLLH (0x0114)
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2021-03-05 Fix Filtered_INS2::correct_yaw() observation H matrix
    The u_1, u_2 elements of q_n2b are correlated to heading in addition to
    u_3.
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2021-07-16 Fix getchar and putchar argument and return types
    [f38x_uart0.c]
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2021-10-27 Fix inverse power method to calculate eigenvectors
2022-07-15 Make separated correction of position and velocity possible
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2023-06-22 Add ctor of dummy distribution to catch std::logic_error
    * Fix in case boost.version for swig is lower than assumed (latest) one.
2023-07-04 Fix SylphideMath.i in case swig and build environments are different
2023-08-29 Add PoR to MS5611 initialization to fix read failure of PROM
    [ms5611.c]
2023-09-26 Fix log_mixer.rb to ignore leading spaces in imu_data(CSV)
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2026-08-13 Fix %append_output in %typemap(out) wrongly inserting nil (> SWIG 4.2)
